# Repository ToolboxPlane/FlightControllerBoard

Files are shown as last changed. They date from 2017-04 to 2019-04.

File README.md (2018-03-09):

View this project on [CADLAB.io](https://cadlab.io/node/744). 

# FlightControllerBoard

A flight controller board for the mini Talon UAV based on a [STM32 Nucleo-32](http://www.st.com/content/st_com/en/products/evaluation-tools/product-evaluation-tools/mcu-eval-tools/stm32-mcu-eval-tools/stm32-mcu-nucleo/nucleo-l432kc.html).

Firmware availiable at [https://github.com/ToolboxBodensee/FlightController](https://github.com/ToolboxBodensee/FlightController).

## PCB
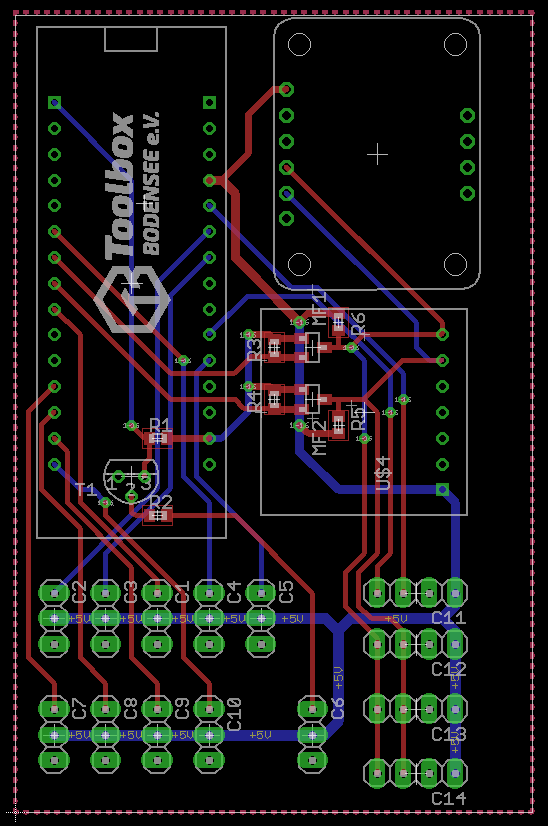
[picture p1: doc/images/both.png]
PCB


### Top layer
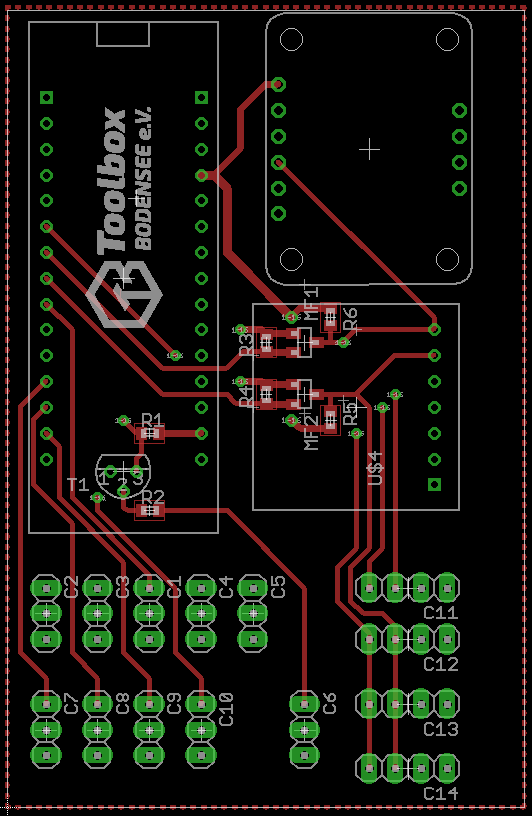
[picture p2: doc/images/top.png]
Top PCB side


### Bottom Layer
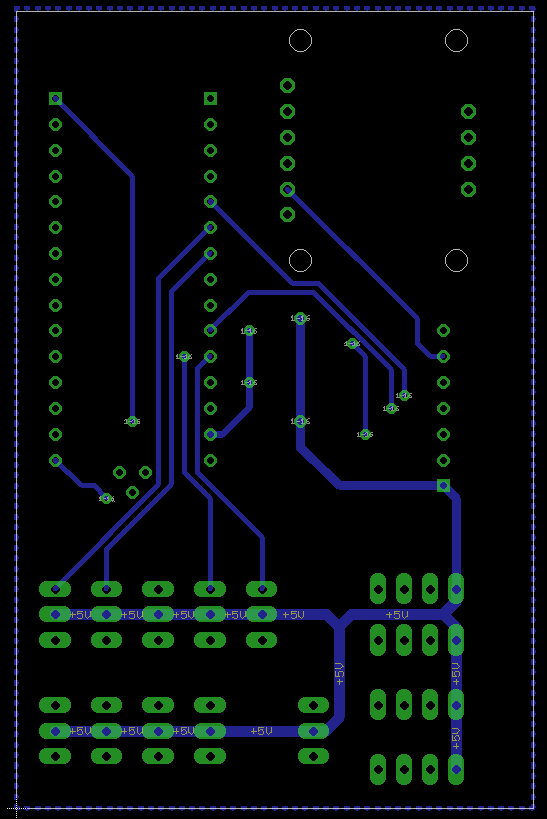
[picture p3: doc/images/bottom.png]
Bottom PCB side


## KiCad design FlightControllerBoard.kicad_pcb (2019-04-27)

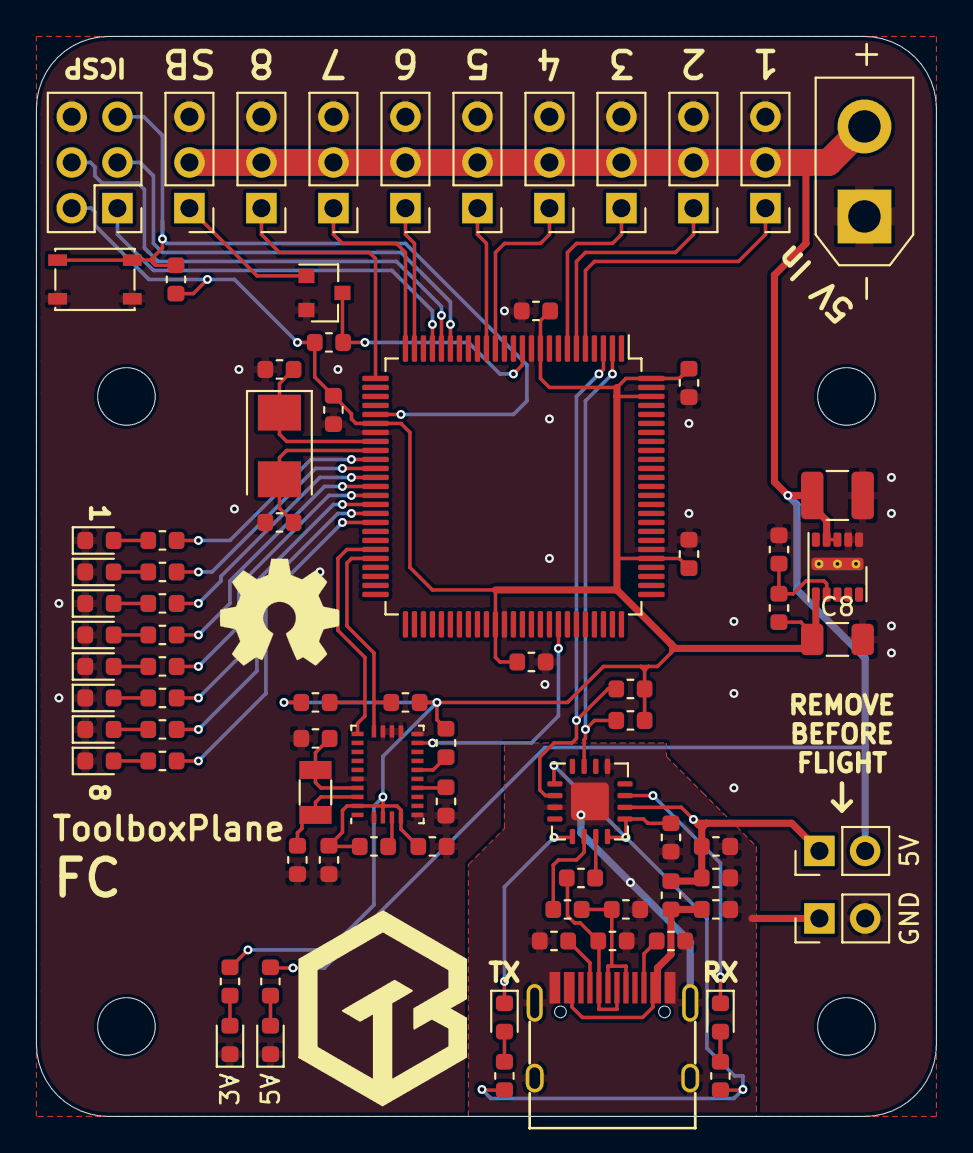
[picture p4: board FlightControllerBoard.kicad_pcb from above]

Board: 2 copper layers, 50.0 x 60.0 mm, 85 parts (0 on the bottom side), 62 nets.

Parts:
C1, C2: 47p; C_0603_1608Metric
C3: 10nF; C_0603_1608Metric
C4, C6, C11, C12, C13, C14, C15, C16, C17, C18: 100nF; C_0603_1608Metric
C5: 4.7µF; C_0603_1608Metric
C7: 10µF; C_1210_3225Metric
C8: 22µF; C_1206_3216Metric
C9, C10: 8pF; C_0603_1608Metric
C19, C20: 9pF; C_0603_1608Metric
D1, D2: LED; LED_0603_1608Metric
D3, D4: LED_Small; LED_0603_1608Metric
D5, D6, D7, D8, D9, D10, D11, D12: LED_0603_1608Metric
FB1: 600 Ohms @ 100MHz; C_0603_1608Metric
H1, H2, H3, H4: MountingHole; MountingHole_3.2mm_M3
J1: Conn_01x02; AMASS_XT30UPB-M_1x02_P5.0mm_Vertical
J2, J3, J4, J5, J6, J7, J8, J9, J10: Conn_01x03_Male; PinHeader_1x03_P2.54mm_Vertical
J11: USB_C_Receptacle_USB2.0; USB_C_Receptacle_GT-USB-7010
J12: Conn_02x03_Odd_Even; PinHeader_2x03_P2.54mm_Vertical
JP1, JP2: Jumper_NO_Small; PinHeader_1x02_P2.54mm_Vertical
Q1: BSS138; SOT-23
R1, R2, R3: 4.7k; R_0603_1608Metric
R4: 470; R_0603_1608Metric
R5, R10, R11: 270; R_0603_1608Metric
R6, R7: 5.1k; R_0603_1608Metric
R8, R9: 27; R_0603_1608Metric
R12: 11.5k; R_0603_1608Metric
R13: 4.99k; R_0603_1608Metric
R14, R23, R24, R25, R26: 10k; R_0603_1608Metric
R15, R16, R17, R18, R19, R20, R21, R22: 100; R_0603_1608Metric
SW1: SW_Push; SW_SPST_PTS810
U1: FT230XQ; QFN-16-1EP_4x4mm_P0.65mm_EP2.1x2.1mm
U2: LMZM23600; Texas_SIL0010A_MicroSiP-10-1EP_3.8x3mm_P0.6mm_EP0.7x2.9mm_T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
U3: ATmega2560-16AU; TQFP-100_14x14mm_P0.5mm
U4: BNO055; LGA-28_5.2x3.8mm_P0.5mm
Y1: 16MHz; Crystal_SMD_5032-2Pin_5.0x3.2mm
Y2: 32.768kHz; Crystal_SMD_3215-2Pin_3.2x1.5mm

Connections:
+3V3: C8.1, C11.2, C12.2, C13.2, C14.2, C15.2, C16.1, C18.1, J12.2, R1.1, R2.1, R3.1, R5.1, R12.1, R14.1, R23.1, R24.1, R25.1, R26.2, U2.6, U3.10, U3.31, U3.61, U3.80, U3.98, U3.100, U4.3, U4.5, U4.28
+5V: C7.1, J1.2, J2.2, J3.2, J4.2, J5.2, J6.2, J7.2, J8.2, J9.2, J10.2, JP1.2, R4.1, U2.3, U2.4
/ATMega/MISO: J12.1, U3.22
/ATMega/MOSI: J12.4, U3.21
/ATMega/RX0: R1.2, U1.15, U3.2
/ATMega/RX1: R23.2, U3.45, U4.20
/ATMega/SCK: J12.3, U3.20
/ATMega/~RESET~: J12.5, R14.2, SW1.2, U3.30
/BNO/INT: U3.68, U4.14
/BNO/RX: R24.2, U3.46, U4.19
/FT230/5VOUT: C4.1, C5.1, FB1.1, JP1.1, U1.10
/FT230/RX: R2.2, U1.2, U3.3
/PWM1: J2.1, U3.24
/PWM2: J3.1, U3.25
/PWM3: J4.1, U3.26
/PWM4: J5.1, U3.5
/PWM5: J6.1, U3.6
/PWM6: J7.1, U3.7
/PWM7: J8.1, U3.15
/PWM8: J9.1, U3.16
/SBUS: J10.1, Q1.1
/~SBUS: Q1.3, R3.2, U3.12
GND: C7.2, C8.2, C9.2, C10.2, C11.1, C12.1, C13.1, C14.1, C15.1, C16.2, C17.1, C18.2, C19.2, C20.2, D1.1, D2.1, D5.1, D6.1, D7.1, D8.1, D9.1, D10.1, D11.1, D12.1, J1.1, J2.3, J3.3, J4.3, J5.3, J6.3, J7.3, J8.3, J9.3, J10.3, J12.6, JP2.2, Q1.2, R13.1, SW1.1, U2.1, U2.2, U2.11, U3.11, U3.32, U3.62, U3.81, U3.99, U4.2, U4.6, U4.15, U4.16, U4.17, U4.18, U4.25
GNDS: C1.2, C2.2, C3.2, C4.2, C5.2, C6.2, J11.A1, J11.A12, J11.B1, J11.B12, J11.S1, JP2.1, R6.1, R7.1, U1.3, U1.13, U1.17
unnamed: C1.1, J11.A7, J11.B7, R8.2
unnamed: C2.1, J11.A6, J11.B6, R9.2
unnamed: C6.1, R10.1, R11.1, U1.1, U1.8, U1.9
unnamed: C9.1, U3.34, Y1.2
unnamed: C10.1, U3.33, Y1.1
unnamed: C17.2, U4.9
unnamed: C19.1, U4.26, Y2.1
unnamed: C20.1, U4.27, Y2.2
unnamed: D1.2, R4.2
unnamed: D2.2, R5.2
unnamed: D3.1, U1.11
unnamed: D3.2, R10.2
unnamed: D4.1, U1.5
unnamed: D4.2, R11.2
unnamed: D5.2, R15.2
unnamed: D6.2, R16.2
unnamed: D7.2, R17.2
unnamed: D8.2, R18.2
unnamed: D9.2, R19.2
unnamed: D10.2, R20.2
unnamed: D11.2, R21.2
unnamed: D12.2, R22.2
unnamed: J11.A5, R6.2
unnamed: J11.B5, R7.2
unnamed: R8.1, U1.7
unnamed: R9.1, U1.6
unnamed: R12.2, R13.2, U2.7
unnamed: R15.1, U3.35
unnamed: R16.1, U3.36
unnamed: R17.1, U3.37
unnamed: R18.1, U3.38
unnamed: R19.1, U3.39
unnamed: R20.1, U3.40
unnamed: R21.1, U3.41
unnamed: R22.1, U3.42
unnamed: R25.2, U4.11
unnamed: R26.1, U4.4
VBUS: C3.1, FB1.2, J11.A4, J11.A9, J11.B4, J11.B9

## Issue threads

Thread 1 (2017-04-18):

Reset Button and connector

ottojo, 2017-04-18:

ottojo, 2017-04-18:
1. Specify Connector
2. Reset button is available on the Nucleo board

aul12, 2017-04-18:
1. A simple two Pin connector which pulls Reset to GND.
2.The button is on the breakout board, if we mount the pcb inside of the plane it isn't possible to use the button

ottojo, 2017-04-18:
added connector

Closed 2017-04-18.

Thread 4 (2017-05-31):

Mounting Holes

ottojo, 2017-05-31:
Top mounting holes are covered by MCU/IMU
Also, they are too close to the pin headers to use a wrench.

Closed 2019-04-03.

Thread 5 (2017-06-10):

Fix SCL Led

aul12, 2017-06-10:
When SCL Led is connected, the scl logic levels get screwed up 0.2V and 1.8V instead of 0 and 3.3/5V

ottojo, 2019-04-03:
Wontfix

Closed 2019-04-03.

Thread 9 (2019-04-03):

Short term TODO

ottojo, 2019-04-03:
- [x] BNO INT Pin on ATMega
- [x] Verify FT230X Schematic matches "Bus Powered" reference implementation
- [x] Verify Pullups on UARTs
- [ ] Eval LMZ21700SILR

aul12, 2019-04-03:
- [ ] Reset Button
- [ ] Move LEDs to Register L

Closed 2019-04-09.

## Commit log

2017-04-17 Sonar, I2C Expansion Ports, Logo, Various Improvements
    [FlightController3.brd, FlightController3.sch]
2017-04-18 changed version to 8.1.1
    [FlightController3.brd, FlightController3.sch]
2017-04-18 fixed toolbox logo
    [FlightController3.brd, FlightController3.sch]
2017-04-18 added reset header
    [FlightController3.brd, FlightController3.sch]
2017-04-18 added mounting holes, removed BNO-055 mounting holes
    [FlightController3.brd, FlightController3.sch]
2017-04-20 power LEDs
    [FlightController3.brd, FlightController3.sch]
2017-04-20 capacitors, dimensions, reset button
    [FlightController3.brd, FlightController3.sch]
2017-04-20 various improvements, mostly silkscreen labels
    [FlightController3.brd, FlightController3.sch]
2017-04-21 fixed naming of D1/D0 and SBUS connection
    [FlightController3.brd, FlightController3.sch]
2017-04-21 removed GPIO, I2C Ports, added expansion port
    [FlightController3.brd, FlightController3.sch]
2017-04-21 smaller board footprint, added reset to port
    [FlightController3.brd, FlightController3.sch]
2017-04-21 rounded edges
    [FlightController3.brd]
2017-04-22 Added SBUS, I²C and UART LEDs
2017-04-23 Fixed several issues
    [FlightController3.brd, FlightController3.sch]
2017-05-11 jumper to select between SBUS and !SBUS
    [FlightController3.brd, FlightController3.sch]
2017-05-11 eeprom and stuff
    [FlightController3.brd, FlightController3.sch]
2017-05-13 various fixes
    [FlightController3.brd]
2017-10-20 updated gitignore to include gerber files
    Source: https://github.com/github/gitignore/blob/master/Eagle.gitignore
2017-10-22 eagle 8.4.0
    [FlightController3.brd, FlightController3.sch]
2017-10-23 sbus inverter spice setup
    [FlightController3.brd, FlightController3.sch]
2017-10-23 i2c level shifting simulation setup
    [FlightController3.brd, FlightController3.sch]
2017-10-23 power led simulation setup
    [FlightController3.brd, FlightController3.sch]
2017-10-23 filtering capacitor simulation setup
    [FlightController3.brd, FlightController3.sch]
2017-10-23 nucleo simulation setup
    [FlightController3.brd, FlightController3.sch]
2017-10-23 EEPROM simulation setup
    [FlightController3.brd, FlightController3.sch]
2017-10-23 signal LED simulation setup
    [FlightController3.brd, FlightController3.sch]
2018-10-20 Started FC4
    [FlightController3.brd, FlightController3.sch, fc.brd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]
2018-10-20 First draft of the schematic finished
    [fc.brd, fc.sch]
2018-10-20 Initial draft for the layout
    [fc.brd, fc.sch]
2018-10-21 Small changes, added reset button
    [fc.brd, fc.sch]
2018-10-30 Improved the design
    [fc.brd, fc.sch]
2018-11-05 FTDI hauptsächlich
    [fc.brd, fc.sch]
2018-11-05 LED alignment
    [fc.brd]
2018-12-02 cleanup
    airwire in pad/alignment
    [fc.brd]
2018-12-02 led placement on grid
    [fc.brd]
2018-12-02 connected LEDs
    [fc.brd]
2018-12-02 led labels
    [fc.brd]
2018-12-02 aligned atmega breakout vias
    [fc.brd]
2018-12-02 atmega breakout cleanup
    [fc.brd]
2018-12-02 isp, reset button, gnd polygon
    [fc.brd]
2018-12-02 reset, alignment, caps
    reset button
    aligned sbus inverter to grid
    moved decoupling cap to sensible position
    [fc.brd]
2018-12-02 minor changes to usb layout
    [fc.brd]
2018-12-02 changed caps to sparkfun lib
    [fc.brd, fc.sch]
2018-12-02 changed LEDs to sparkfun lib
    [fc.brd, fc.sch]
2018-12-02 changed resistors to sparkfun lib
    how nice, all the 0603 parts are the same size now.
    [fc.brd, fc.sch]
2018-12-02 move led resistors up
    [fc.brd]
2018-12-02 fixed obviously wrong DRC errors
    (?)
    [fc.brd]
2019-04-03 And Now for Something Completely Different
    [3V3.sch, ATMega.sch, BNO055.sch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]
2019-04-03 LMZM23600 from official kicad lib
    [3V3.sch, ATMega.sch, BNO055.sch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]
2019-04-03 update PCB to match schematic changes
    [FlightControllerBoard.kicad_pcb]
2019-04-04 use submodule for FT230
    [3V3.sch, ATMega.sch, BNO055.sch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]
2019-04-04 pullups, jumpers
    [3V3.sch, ATMega.sch, BNO055.sch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]
2019-04-05 LED, Mounting Holes
    LEDs to register L
    Mounting Holes
    XT30
    [ATMega.sch, FlightControllerBoard.sch]
2019-04-06 fix Y1 connection
    [FlightControllerBoard.kicad_pcb]
2019-04-06 small layout fixes
    [3V3.sch, BNO055.sch, FlightControllerBoard.kicad_pcb]
2019-04-07 silkscreen logos
    [FlightControllerBoard.kicad_pcb]
2019-04-07 rebuild zones
    [FlightControllerBoard.kicad_pcb]
2019-04-07 fix power input
    [FlightControllerBoard.kicad_pcb]
2019-04-07 optimize gnd connections
    [FlightControllerBoard.kicad_pcb]
2019-04-07 added NCs to satisfy ERC
    [ATMega.sch, BNO055.sch, FlightControllerBoard.sch]
2019-04-27 fix LED resistor values
    [ATMega.sch, FlightControllerBoard.kicad_pcb]
